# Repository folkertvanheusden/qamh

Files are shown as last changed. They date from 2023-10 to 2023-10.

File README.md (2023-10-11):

qamh
----

NOTE: do not use older than version 0.3!

NOTE: THE NOTCH OF THE POWERCONNECTOR (only the notch) IS ON THE WRONG SIDE!!!

Due to the unavailability for a long time already of the Grains module, I decided to recreate the device.
This repo contains the Kicad schematics and PCB design.
It is not a literal conversion: some features were added and the layout is different.

This device is an Eurorack/Doepfer-A100 modulair-synthesizer module. It allows you to upload your own firmware and then produce whatever effect you want it to do.

I found a modification on the web where someone put a piezo on pin 6 of the Arduino (Nano), for that I added a header (GND + D6).

I did *not* look at the original PCB, only at the documentation I found on the web ( https://www.thonk.co.uk/shop/ginkosynthese-grains-full-diy-kit/ ).

The design should be compatible with the original Grains module and should be able to run the original software without modifications.

This design is released under the CC0 license, but do with it whatever you want.

Clone this repo using "--recurse-submodules" as it contains submodules.

Please note: this is work in progress. At the point of writing this (October 7, 2023) the design was not tested.

Modifications:
* D2 can be connected to a button
* D6 can be connected to a piezo buzzer

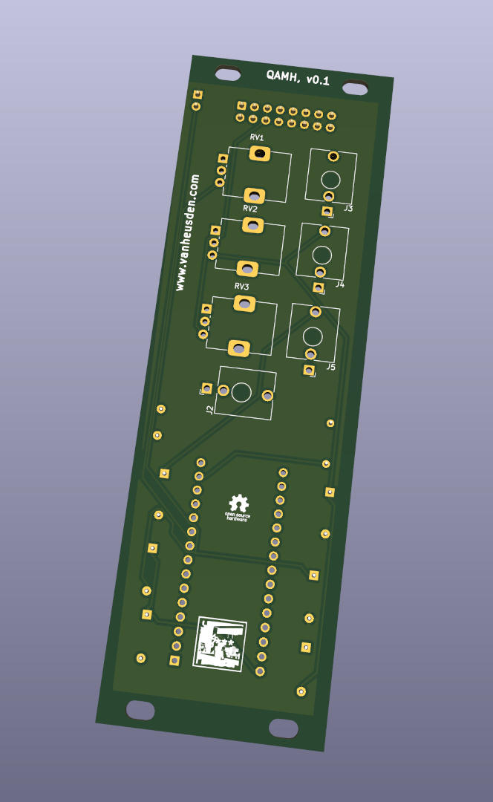
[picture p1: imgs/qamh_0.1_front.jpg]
front


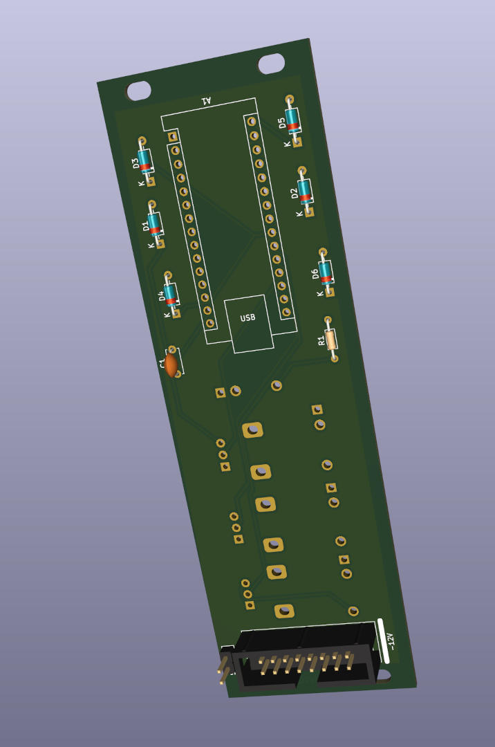
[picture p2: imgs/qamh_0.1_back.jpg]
back


Folkert van Heusden <mail@vanheusden.com>

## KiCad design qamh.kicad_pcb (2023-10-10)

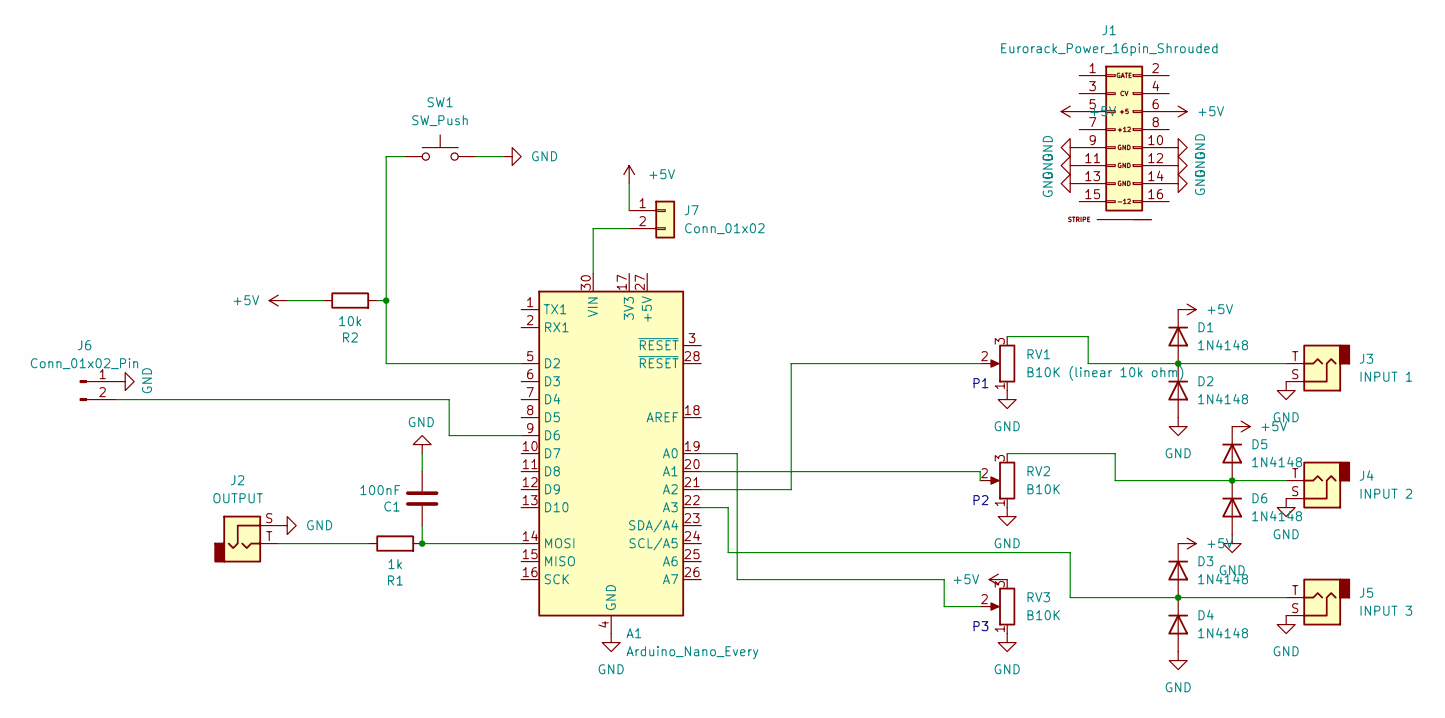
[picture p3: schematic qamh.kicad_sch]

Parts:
A1: Arduino_Nano_Every; Arduino_Nano
C1: 100nF; C_Disc_D5.0mm_W2.5mm_P5.00mm
D1, D2, D3, D4, D5, D6: 1N4148; D_DO-35_SOD27_P7.62mm_Horizontal
J1: Eurorack_Power_16pin_Shrouded; Pins_2x08_2.54mm_TH_EuroPower_Shrouded; Part Number LL1007-1 (2*8 HITEMP)
J2: OUTPUT; Jack_3.5mm_QingPu_WQP-PJ398SM_Vertical_CircularHoles
J3: INPUT 1; Jack_3.5mm_QingPu_WQP-PJ398SM_Vertical_CircularHoles
J4: INPUT 2; Jack_3.5mm_QingPu_WQP-PJ398SM_Vertical_CircularHoles
J5: INPUT 3; Jack_3.5mm_QingPu_WQP-PJ398SM_Vertical_CircularHoles
J6: Conn_01x02_Pin; PinHeader_1x02_P2.54mm_Vertical
J7: Conn_01x02; PinHeader_1x02_P2.54mm_Vertical; Part Number 1-0201FBV0T
R1: 1k; R_Axial_DIN0204_L3.6mm_D1.6mm_P7.62mm_Horizontal
R2: 10k; R_Axial_DIN0204_L3.6mm_D1.6mm_P7.62mm_Horizontal
RV1: B10K (linear 10k ohm); Potentiometer_Alps_RK09K_Single_Vertical
RV2, RV3: B10K; Potentiometer_Alps_RK09K_Single_Vertical
SW1: SW_Push; SW_PUSH_6mm_H5mm

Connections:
+5V: D1.1 (K), D3.1 (K), D5.1 (K), J1.5 (+12V), J1.6, J7.1, R2.1, RV3.3
GND: A1.4 (GND), A1.29 (GND), C1.2, D2.2 (A), D4.2 (A), D6.2 (A), J1.9 (GND), J1.10 (GND), J1.11 (GND), J1.12 (GND), J1.13 (-12), J1.14 (-12V), J2.S, J3.S, J4.S, J5.S, J6.1, RV1.1, RV2.1, RV3.1, SW1.2
unnamed: A1.19 (A0), RV3.2
unnamed: A1.20 (A1), RV2.2
unnamed: A1.21 (A2), RV1.2
unnamed: A1.22 (A3), D3.2 (A), D4.1 (K), J5.T
unnamed: A1.5 (D2), R2.2, SW1.1
unnamed: A1.9 (D6), J6.2
unnamed: A1.14 (MOSI), C1.1, R1.2
unnamed: A1.30 (VIN), J7.2
unnamed: D1.2 (A), D2.1 (K), J3.T, RV1.3
unnamed: D5.2 (A), D6.1 (K), J4.T, RV2.3
unnamed: J2.T, R1.1

Board: 2 copper layers, 21 parts (12 on the bottom side), 13 nets, no tracks yet.

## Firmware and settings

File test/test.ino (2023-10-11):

void setup() {
	Serial.begin(115200);

	pinMode(11, OUTPUT);
}

int freq = 1;

void loop() {
	Serial.print(analogRead(A0));
	Serial.print('\t');
	Serial.print(analogRead(A1));
	Serial.print('\t');
	Serial.print(analogRead(A2));
	Serial.print('\t');
	Serial.println(analogRead(A3));

	tone(11, freq++);

	freq &= 4095;
}

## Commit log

2023-10-06 fix (2) pot
    [qamh.kicad_pcb, qamh.kicad_sch]
2023-10-07 power needs to be fed via the vin of the nano
    [qamh.kicad_pcb, qamh.kicad_sch]
2023-10-07 logo's, header for piezo
    [qamh.kicad_pcb, qamh.kicad_sch]
2023-10-07 potmeters are B10k (linear 10k ohm)
    [qamh.kicad_sch]
2023-10-07 will be rebuild by kicad
2023-10-07 meta data in sheet
    [qamh.kicad_sch]
2023-10-09 added button to D2
    [qamh.kicad_pcb, qamh.kicad_sch]
2023-10-10 header for plug/unplug 5V
    [qamh.kicad_pcb, qamh.kicad_sch]
2023-10-11 audible test-signal on pin 11
